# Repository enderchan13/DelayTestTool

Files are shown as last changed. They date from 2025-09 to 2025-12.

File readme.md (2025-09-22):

# 磁轴键盘延时测试器

## 概述

磁轴键盘延时测试器是一个专为磁轴键盘设计的自动化测试工具，用于精确测量按键的**按下延迟**和**抬起延迟**。它通过**通电线圈模拟磁铁**，用曲线拟合人手按压和释放过程，避免市面上使用机械按压结构加摄像机分帧的测量方式造成的静态误差和随机干扰，整个过程精准可控且最大限度贴近人手使用模式。除了可测量单键的全链路延迟之外，也支持多键和SOCD的延时测试。测试器通过多次快速触发测量平均延迟，提供高精度、可重复的测试结果。本项目适用于键盘制造商、硬件测试人员及键盘爱好者。

## 功能特性

- **极限工况测试**：支持极限快速、极限低速、真实按压等多种不同测试工况的模拟测试
- **自动化测试**：通过通电线圈模拟磁铁触发磁轴开关，消除手动按压的不一致性
- **高精度测量**：支持微秒级延迟检测（精度可达±0.1ms）
- **可重复测试**：支持多次快速触发，计算平均延迟
- **兼容性**：支持常见磁轴键盘（如霍尔效应、磁感应开关）
- **数据显示**：测试结果将直接展示在测试器屏幕

## 系统架构

### 硬件组件

1. **主控制器**：沁恒CH32V305RBT6（支持USB HID通信）
2. **线圈驱动电路**：LDO电路（如D2652-AD）控制通电线圈模拟磁铁动作
3. **线圈驱动接口**：直接连接线圈轴体
4. **电源接口**：直接连接5V/2A直流电源（为线圈和控制器供电）
4. **PC接口**：直接连接电脑（可进行测试器固件升级更新）
4. **USB主机接口**：直接连接待测试磁轴键盘（对键盘进行延时测试）

### 软件组件

1. **固件**（C/C++）：识别接入到测试器的磁轴键盘，控制线圈触发时序对键盘进行延时测试
2. **测试逻辑**：
   - 识别接入的待测试键盘
   - 发送触发信号并记录时间戳
   - 计算按下延迟（从线圈磁场模拟按下到键盘发送按下报文）和抬起延迟（从线圈磁场模拟释放到键盘发送抬起报文）
   - 循环多次测试并统计结果

## 安装与使用

### 硬件连接

1. 将线圈固定在磁轴键盘的待测按键上方（确保与磁轴对齐）
2. 连接线圈到线圈驱动接口
3. 电源供电（5V适配器或USB）
4. 连接磁轴键盘到测试器USB主机接口（USB线）

### 固件升级

1. 安装WCHISPTool_Setup（安装包路径Tools/WCHISPTool_Setup）
2. 打开本项目固件文件 `BinFiles/DelayTestTool_v0.0.2_20250912a`
3. 按下BOOT按键连接到WCH芯片
4. 下载固件

### 文档资料

1. 测试器硬件原理图、PCB以及BOM资料路径/Docs/Hardware/
2. 测试器操作说明资料路径/Docs/UserManual/
3. 测试器操作教程、升级教程以及原理讲解视频资料路径/Docs/Vedio/

### 使用说明
- 测试器使用步骤详情见Docs/UserManual/<延时测试器操作说明.pdf>

## 许可证
- 本项目根据**GNU通用公共许可证v2.0**或者更高版本授权。
- 完整的许可证文本请参阅**LICENSE**文件。

## 注意事项
1. 安全使用：线圈驱动过久会发热严重，请谨慎操作，避免烫伤
2. 校准建议：首次使用时需根据键盘类型进行按键校准和测试模式配置（详情见 Docs/<延时测试器操作说明.pdf>）
3. 兼容性：目前支持常见磁轴键盘（如XSYD、Wooting、MelGeek等）
4. 故障排除：如果测试结果异常，检查线圈轴体是否安装到位或者或者其他错误操作（详情见Docs/<延时测试器操作说明.pdf>）

## 致谢
- 灵感来自磁轴键盘测试需求及开源社区讨论

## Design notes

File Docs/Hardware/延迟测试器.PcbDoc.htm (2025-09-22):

Reporting Options

# File in Newer Format

Date | : | 2025/9/22
Time | : | 10:21:12
Filename | : | E:\repository\DelayTestTool\Docs\Hardware\延迟测试器.PcbDoc

Version | Warning
Release 23.6 | CAUTION - The PCB document contains Footprint parameters. These will be lost when opening the document in a version of Altium Designer that does not support this functionality.

This file was generated by a later version of the software

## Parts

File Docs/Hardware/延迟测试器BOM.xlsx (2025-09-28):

延迟测试器BOM
Class | Comment | Description | Designator | Footprint | Quantity | interlinkage | picture | PS
贴片电容 | 1000pF/2kV | 1000pF/K/2KV/X7R/1206 | C1, C11 | C 1206_L | 2 | https://so.szlcsc.com/global.html?k=C9196&hot-key=STM32F103C8T6
贴片电容 | 100nF | 100nF/±10%/50V/X7R/0603 | C2, C3, C10, C14, C15, C16, C17, C23, C26 | C 0603_L | 9 | https://so.szlcsc.com/global.html?k=C14663&hot-key=STM32F103C8T6
钽电容 | 22uF钽电容 | 22uF/±10%/CA45/A/10V/1206 | C4, C5, C21 | CDA1206 | 3 | https://so.szlcsc.com/global.html?k=C6143460&hot-key=STM32F103C8T6
钽电容 | 47uF钽电容 | 47uF/±10%/CA45/B/10V/3528 | C6 | CD B(3528) | 1 | https://so.szlcsc.com/global.html?k=C123253&hot-key=STM32F103C8T6
贴片电容 | 10uF | 10uF/±10%/10V/X5R/0603 | C9, C18, C19, C20, C22 | C 0603_L | 5 | https://so.szlcsc.com/global.html?k=C19702&hot-key=STM32F103C8T6
贴片电容 | 12pF | 12pF/±5%/50V/NPO/0603 | C12, C13 | C 0603_L | 2 | https://so.szlcsc.com/global.html?k=C107034&hot-key=STM32F103C8T6
贴片电阻 | 10k | 10k/±5%/100mW/75V/±100ppm/℃/0603 | R1, R7, R15, R17, R18, R19, R20, R22, R23, R24 | R 0603_L | 10 | https://so.szlcsc.com/global.html?k=C2930027&hot-key=STM32F103C8T6
贴片电阻 | 1M | 1M/±5%/1206 | R2, _x0003_R1 | R 1206_L | 2 | https://so.szlcsc.com/global.html?k=C2907441&hot-key=STM32F103C8T6
贴片电阻 | 1k | 1k/±5%/1/10W/0603 | R5, R10, R21 | R 0603_L | 3 | https://so.szlcsc.com/global.html?k=C22356624&hot-key=STM32F103C8T6
贴片电阻 | 62R | 62R/±5%/1/10W/0603 | R8 | R 0603_L | 1 | https://so.szlcsc.com/global.html?k=C2907193&hot-key=STM32F103C8T6
贴片电阻 | 5.1k | 5.1k/±5%/1/10W/0603 | R9, R13, R14, R16 | R 0603_L | 4 | https://so.szlcsc.com/global.html?k=C26000&hot-key=STM32F103C8T6
贴片电阻 | 0R | 0R/±5%/1/10W/0603 | R11, R12, R25, R26 | R 0603_L | 4 | https://so.szlcsc.com/global.html?k=C2907080&hot-key=STM32F103C8T6
磁珠 | 90R/100MHZ/NC | 90R/100MHZ/NC | L1, L3 | 2012-L | 0 |  |  | NC
IC | CE6210A33P | CE6210A33P/SOT89-3 | U1 | SOT89-3 | 1 | 【淘宝】https://e.tb.cn/h.SX97oUnxk7mCEgo?tk=crG34ufWmXE MF278 「CE6210A33P 封装SOT89-3 LDO稳压IC 原装」
MCU | CH32V305RBT6 | CH32V305RBT6/LQFP64 10x10_M | U2 | LQFP64 10x10_M | 1 | https://so.szlcsc.com/global.html?k=C5187529&hot-key=STM32F103C8T6
TVS管 | USBLC6-2SC6 | USBLC6-2SC6/TVS管/SOT23-6 | D1 | SOT23-6M | 1 | https://so.szlcsc.com/global.html?k=C2827654&hot-key=STM32F103C8T6
晶振 | 24MHZ | Y3225/24MHZ/12pF/10ppM | X1 | OSC 3225-4P | 1 | https://so.szlcsc.com/global.html?k=C164058&hot-key=STM32F103C8T6
TYPE-C | USB TYPE C | TYPE C 16PIN板上型7.35MM 三模母座 带弹片 短舌口 | USB1, USB2 | TYPE-C 16PIN 2MD(073) | 2 | https://so.szlcsc.com/global.html?k=C2840391&hot-key=STM32F103C8T6
TYPE-C | USB母座 | USB-A型母接口 | USB3 | USB-A/S_B | 1 | https://so.szlcsc.com/global.html?k=C404963&hot-key=STM32F103C8T6 | =DISPIMG("ID_FE9C9ED8A97D4D97BB3E7B776DAC5DDF",1)
轻触开关 | 3x6x5 | TS-1009S-03826/3x6x5轻触开关支架 | SW1 | SW-SMD_L6.0-W3.3-LS8.0 | 1 | https://so.szlcsc.com/global.html?k=C18078124&hot-key=STM32F103C8T6 | =DISPIMG("ID_B56FF27C85AE4D59906D2A8A2305ED9A",1)
轻触开关 | 3x6x5 | 3x6x5轻触开关/TS-1101-C-W | SW2, SW3, SW4, SW5 | SW-TH_4P-L7.4-W5.0-P5.0 | 4 | https://so.szlcsc.com/global.html?k=C318938&hot-key=STM32F103C8T6 | =DISPIMG("ID_A550F3A074CA4E69AD2A6719362A980A",1)
肖特基二极管 | SS24 | SS24/肖特基二极管/SMA | D2, D3 | SMA | 2 | https://so.szlcsc.com/global.html?k=C7420362&hot-key=STM32F103C8T6
FPC连接器 | 屏幕接口 | FPC0.5*8P/抽屉式/下接/卧贴 | FPC1 | FPC-SMD_AFC07-S08FCA-00 | 1 | https://so.szlcsc.com/global.html?k=C262555&hot-key=STM32F103C8T6
高频放大-PNP型 | SS8550 | SS8550/SOT23L | Q1 | SOT23L | 1 | https://so.szlcsc.com/global.html?k=C916393&hot-key=STM32F103C8T6
LDO | D2652-AD | D2652-AD/TO-263-5 | U3 | TO-263-5_L10.2-W8.9-P1.70-TL-LS15.2 | 1 | https://so.szlcsc.com/global.html?k=C2837289&hot-key=STM32F103C8T6
DC002母头 | DC-002-2.0A-1.3 | DC-002-2.0A-1.3/DC002母头 | DC1 | DC-IN-TH_DC-002-2.0A-1.3 | 1 | https://item.taobao.com/item.htm?_u=p2bbhg32ebef&id=723232233042&skuId=5025121028404 | =DISPIMG("ID_BE2CEAD91BA34B32A4C57BDFE3A3CF18",1)
双通铜柱 | M2*8mm | M2*8mm/双通铜柱 | / | / | 4 | https://detail.tmall.com/item.htm?from=cart&id=16356181954&skuId=5053912691569&upStreamPrice=189 | =DISPIMG("ID_EE856DFD05E440A9B50BE96DF4F012FB",1)
双通铜柱 | M2*5+3mm | M2*5+3mm/双通铜柱 | / | / | 4 | https://detail.tmall.com/item.htm?from=cart&id=16356181954&skuId=5053912691564&upStreamPrice=189 | =DISPIMG("ID_C07D0C5867C04F448279E9EA2559F678",1)
十字圆头螺丝 | M2*4mm | M2*4mm/十字圆头螺丝 | / | / | 8 | https://detail.tmall.com/item.htm?from=cart&id=17088123342&skuId=4890861585220&upStreamPrice=469 | =DISPIMG("ID_9D3E65D7E90D44AEA3553F17F033701D",1)
DC002公头带线 | DC3.5x1.35公头线-30CM | DC3.5x1.35公头线-30CM | / | / | 1 | https://item.taobao.com/item.htm?_u=p2bbhg32e2a0&id=614222721679&skuId=4496351122376 | =DISPIMG("ID_CDFD7AB1DBFA4879A2FF8B23AB24BD7A",1)
彩色热塑管 | φ2mm | φ2mm/长度45mm | / | / | 1 | https://detail.tmall.com/item.htm?id=735286048821
彩色热塑管 | φ5mm | φ5mm/长度45mm | / | / | 1 | https://detail.tmall.com/item.htm?id=735286048821
彩色热塑管 | φ10mm | φ10mm/长度45mm | / | / | 1 | https://detail.tmall.com/item.htm?id=735286048821
屏幕 | 1.14 | 1.14/屏幕 | / | / | 1 | 【淘宝】https://e.tb.cn/h.SXrZcfo6Hd8iDyt?tk=ZNrl4u4WRug HU293 「1.14寸TFT液晶屏st7789驱动135x240高清显示LCD长条形屏SPI彩屏幕」 点击链接直接打开 或者 淘宝搜索直接打开 | =DISPIMG("ID_6B6917046DC74415807B5AD36ADE6ADC",1)
亚克力板子 | 54.2*35.2*2mm | 54.2*35.2*2mm/亚克力板子 | / | / | 2 | 【淘宝】7天无理由退货 https://e.tb.cn/h.SWVldsaU9S1TlKb?tk=qae54vo9EIr CZ057 「定制加工高透明亚克力板有机玻璃塑料板热弯印刷雕刻展示盒PMMA板」 点击链接直接打开 或者 淘宝搜索直接打开 | =DISPIMG("ID_838DD5E48F22457A873292679A285B84",1)
线圈 | 定制 |  | / | 用猛锌铁氧体材料，直径6mm*长度39mm，用0.4mm的漆包线绕5层（找客服定制） | 1 | 【淘宝】https://e.tb.cn/h.S4bxYEJ5Le5NJKq?tk=TJ4y4xEsE35 HU108 「中周成品定制 线圈定制 调幅中波中周中频变压器 可调节磁帽磁芯」 点击链接直接打开 或者 淘宝搜索直接打开 | =DISPIMG("ID_3CDE111D44D54F87A5B2880B30020D5A",1)
PCBA尺寸：54.2mm*35.18mm

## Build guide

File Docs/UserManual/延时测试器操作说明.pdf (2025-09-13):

## 延时测试器操作说明

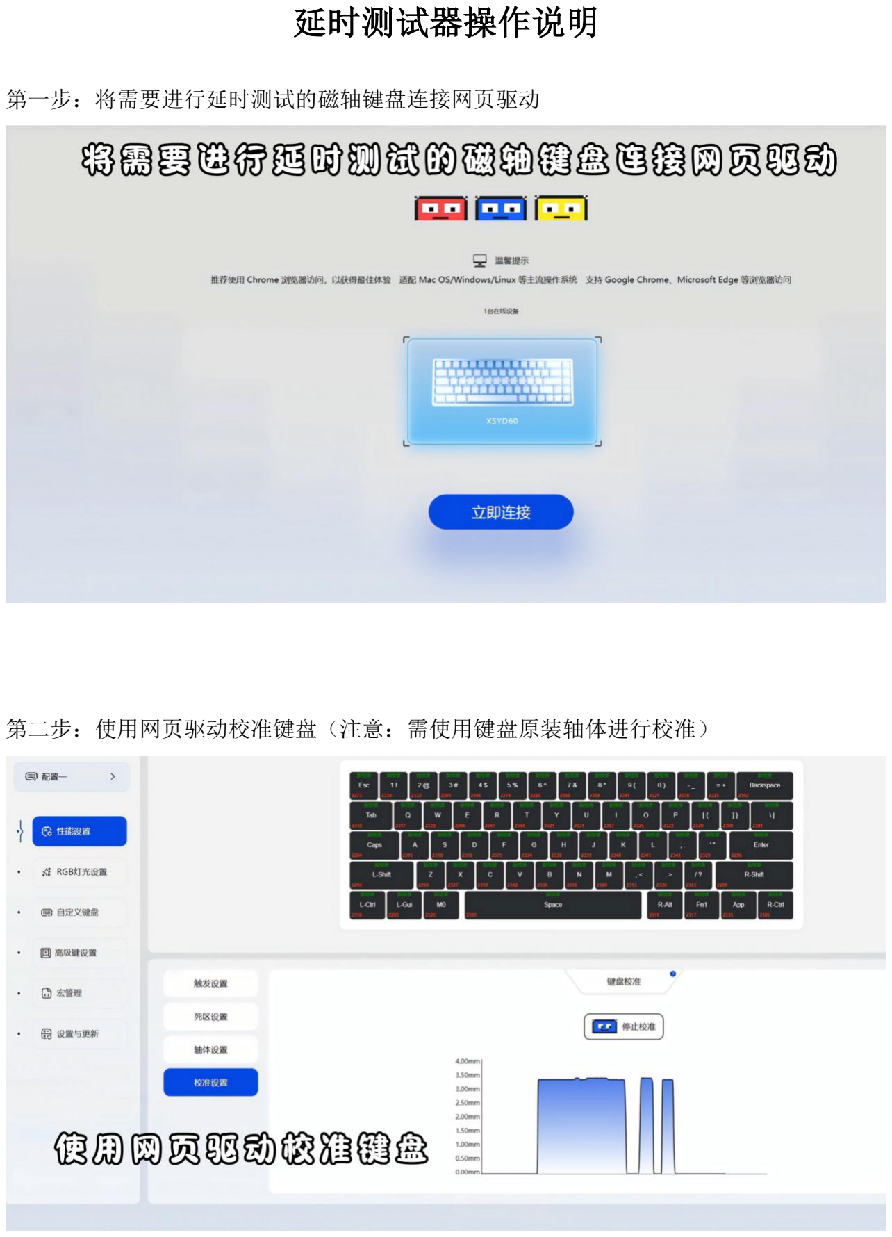
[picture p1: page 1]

第一步：将需要进行延时测试的磁轴键盘连接网页驱动

第二步：使用网页驱动校准键盘（注意：需使用键盘原装轴体进行校准）

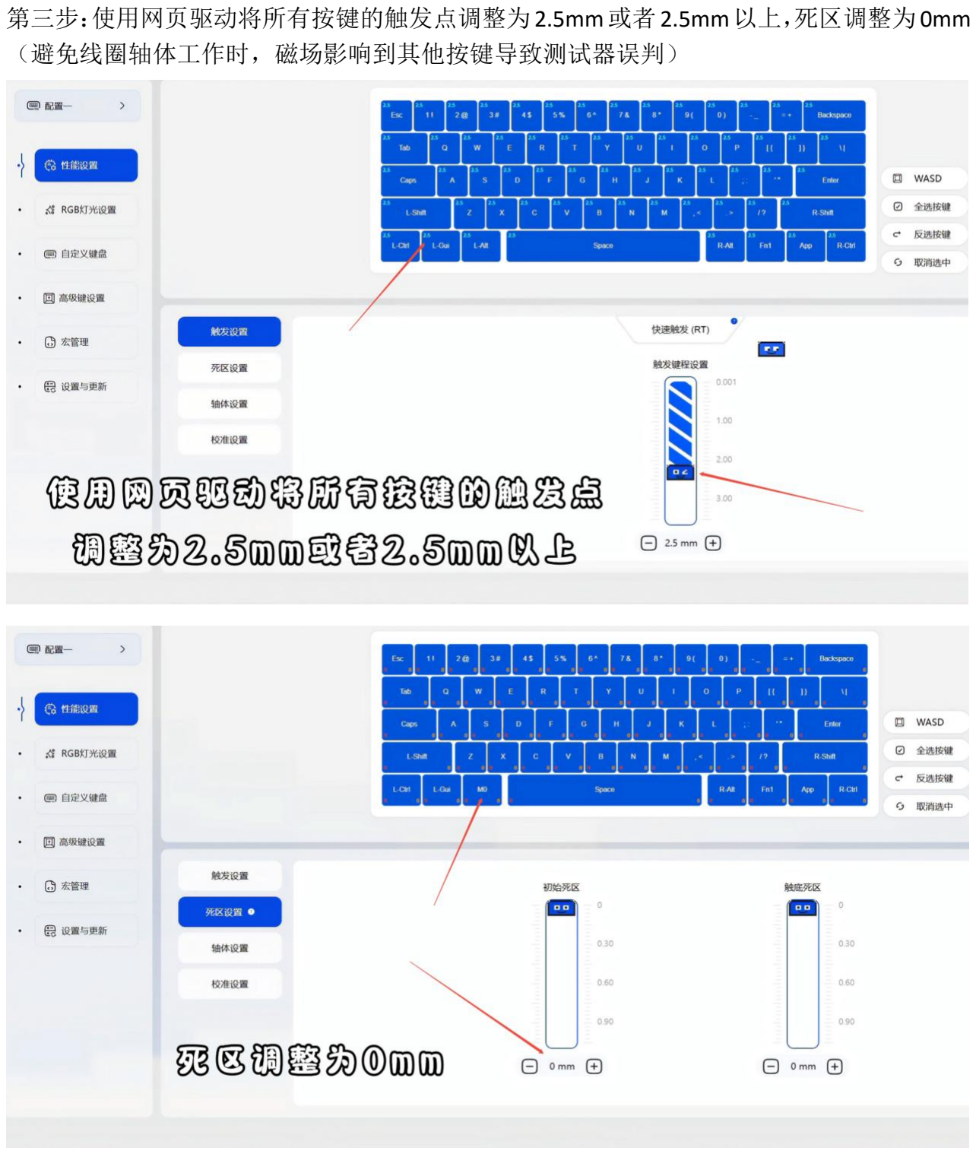
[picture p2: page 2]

第三步：使用网页驱动将所有按键的触发点调整为2.5mm或者2.5mm以上，死区调整为0mm （避免线圈轴体工作时，磁场影响到其他按键导致测试器误判）

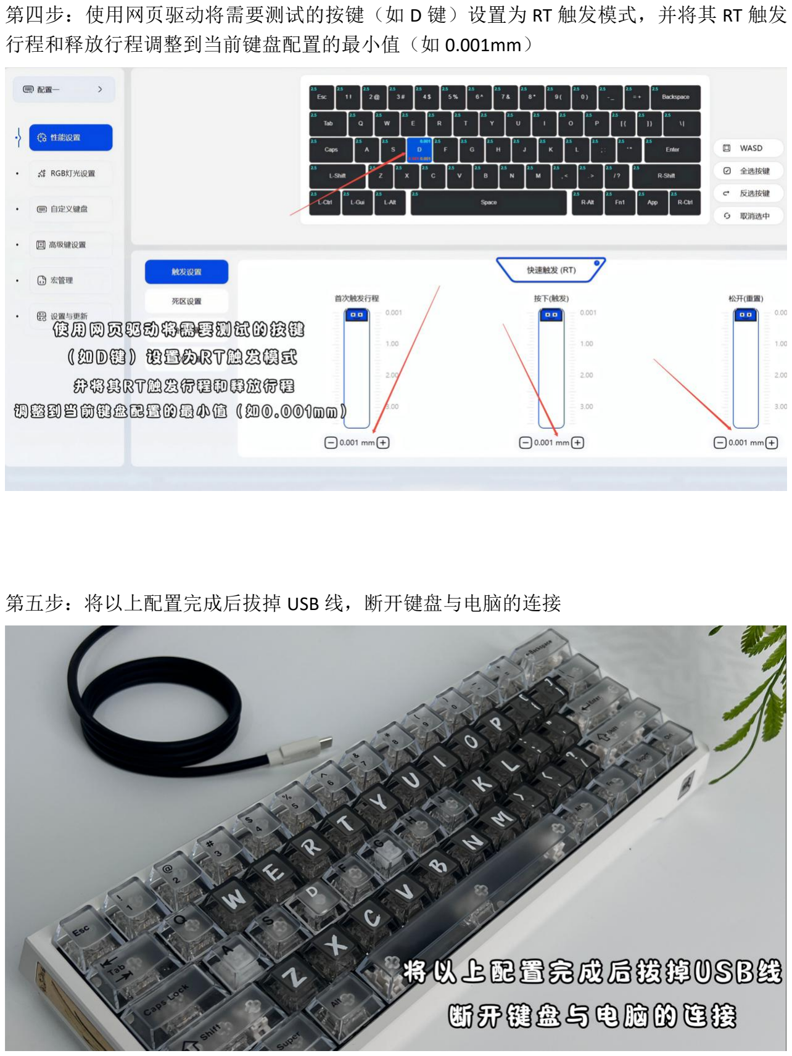
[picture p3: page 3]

第四步：使用网页驱动将需要测试的按键（如 D 键）设置为 RT 触发模式，并将其 RT 触发 行程和释放行程调整到当前键盘配置的最小值（如 0.001mm）

第五步：将以上配置完成后拔掉 USB 线，断开键盘与电脑的连接

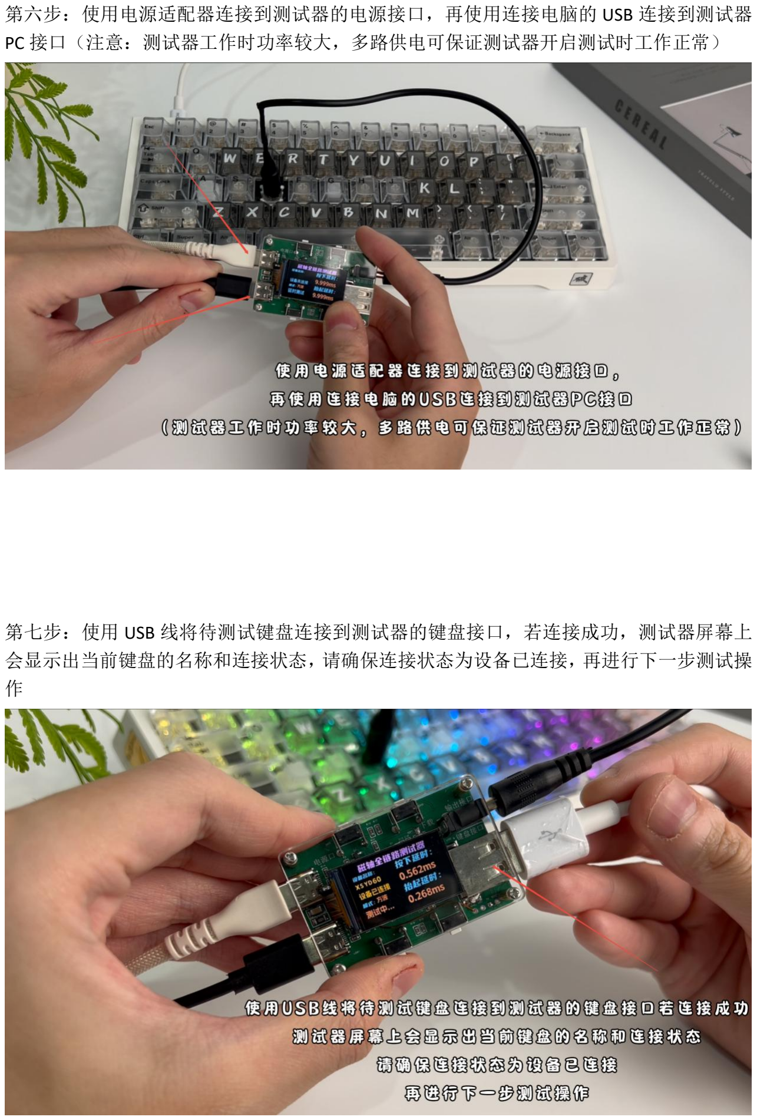
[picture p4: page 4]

第六步：使用电源适配器连接到测试器的电源接口，再使用连接电脑的 USB 连接到测试器 PC 接口（注意：测试器工作时功率较大，多路供电可保证测试器开启测试时工作正常）

第七步：使用 USB 线将待测试键盘连接到测试器的键盘接口，若连接成功，测试器屏幕上 会显示出当前键盘的名称和连接状态，请确保连接状态为设备已连接，再进行下一步测试操 作

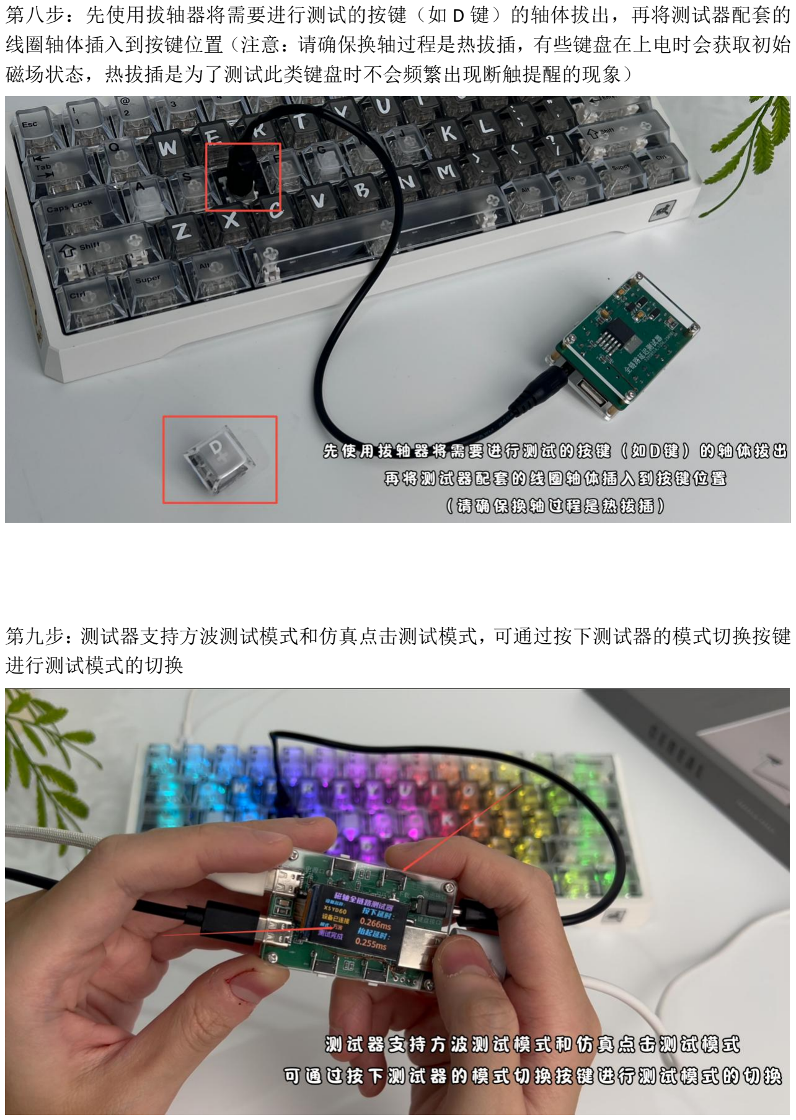
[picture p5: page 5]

第八步：先使用拔轴器将需要进行测试的按键（如 D 键）的轴体拔出，再将测试器配套的 线圈轴体插入到按键位置（注意：请确保换轴过程是热拔插，有些键盘在上电时会获取初始 磁场状态，热拔插是为了测试此类键盘时不会频繁出现断触提醒的现象）

第九步：测试器支持方波测试模式和仿真点击测试模式，可通过按下测试器的模式切换按键 进行测试模式的切换

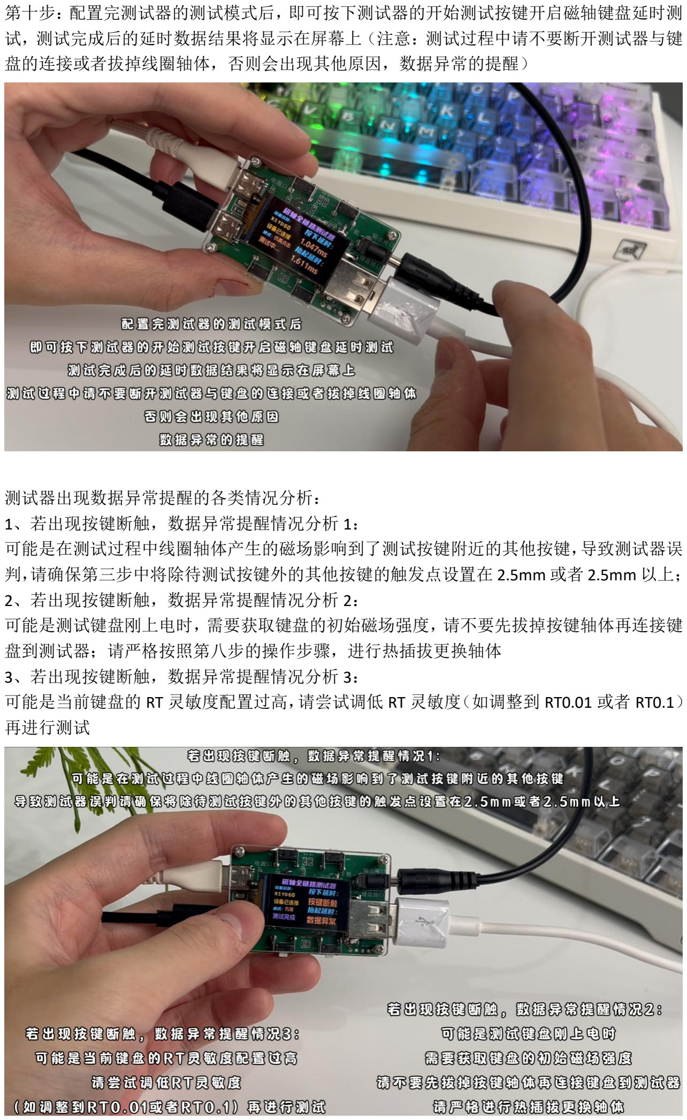
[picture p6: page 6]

第十步：配置完测试器的测试模式后，即可按下测试器的开始测试按键开启磁轴键盘延时测 试，测试完成后的延时数据结果将显示在屏幕上（注意：测试过程中请不要断开测试器与键 盘的连接或者拔掉线圈轴体，否则会出现其他原因，数据异常的提醒）

测试器出现数据异常提醒的各类情况分析：
1、若出现按键断触，数据异常提醒情况分析 1：
可能是在测试过程中线圈轴体产生的磁场影响到了测试按键附近的其他按键，导致测试器误 判，请确保第三步中将除待测试按键外的其他按键的触发点设置在 2.5mm 或者 2.5mm 以上； 2、若出现按键断触，数据异常提醒情况分析 2：
可能是测试键盘刚上电时，需要获取键盘的初始磁场强度，请不要先拔掉按键轴体再连接键 盘到测试器；请严格按照第八步的操作步骤，进行热插拔更换轴体 3、若出现按键断触，数据异常提醒情况分析 3：
可能是当前键盘的 RT 灵敏度配置过高，请尝试调低 RT 灵敏度（如调整到 RT0.01 或者 RT0.1） 再进行测试

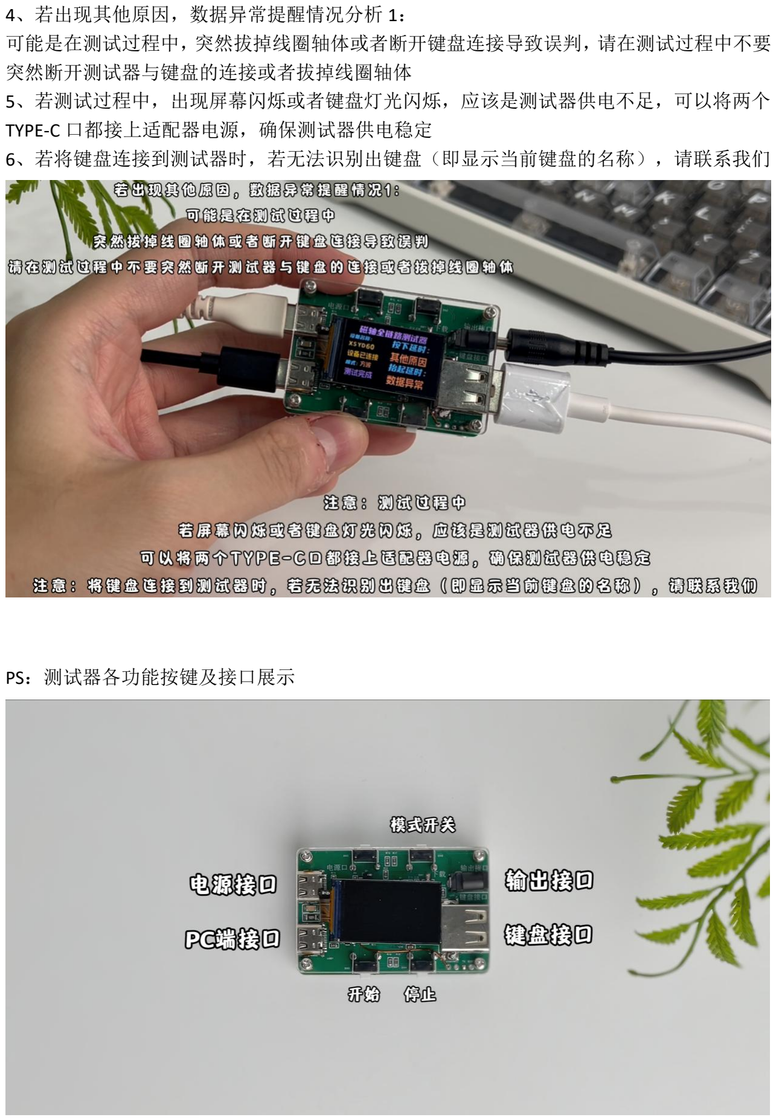
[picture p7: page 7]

4、若出现其他原因，数据异常提醒情况分析 1：
可能是在测试过程中，突然拔掉线圈轴体或者断开键盘连接导致误判，请在测试过程中不要 突然断开测试器与键盘的连接或者拔掉线圈轴体
5、若测试过程中，出现屏幕闪烁或者键盘灯光闪烁，应该是测试器供电不足，可以将两个 TYPE-C 口都接上适配器电源，确保测试器供电稳定 6、若将键盘连接到测试器时，若无法识别出键盘（即显示当前键盘的名称），请联系我们

PS：测试器各功能按键及接口展示

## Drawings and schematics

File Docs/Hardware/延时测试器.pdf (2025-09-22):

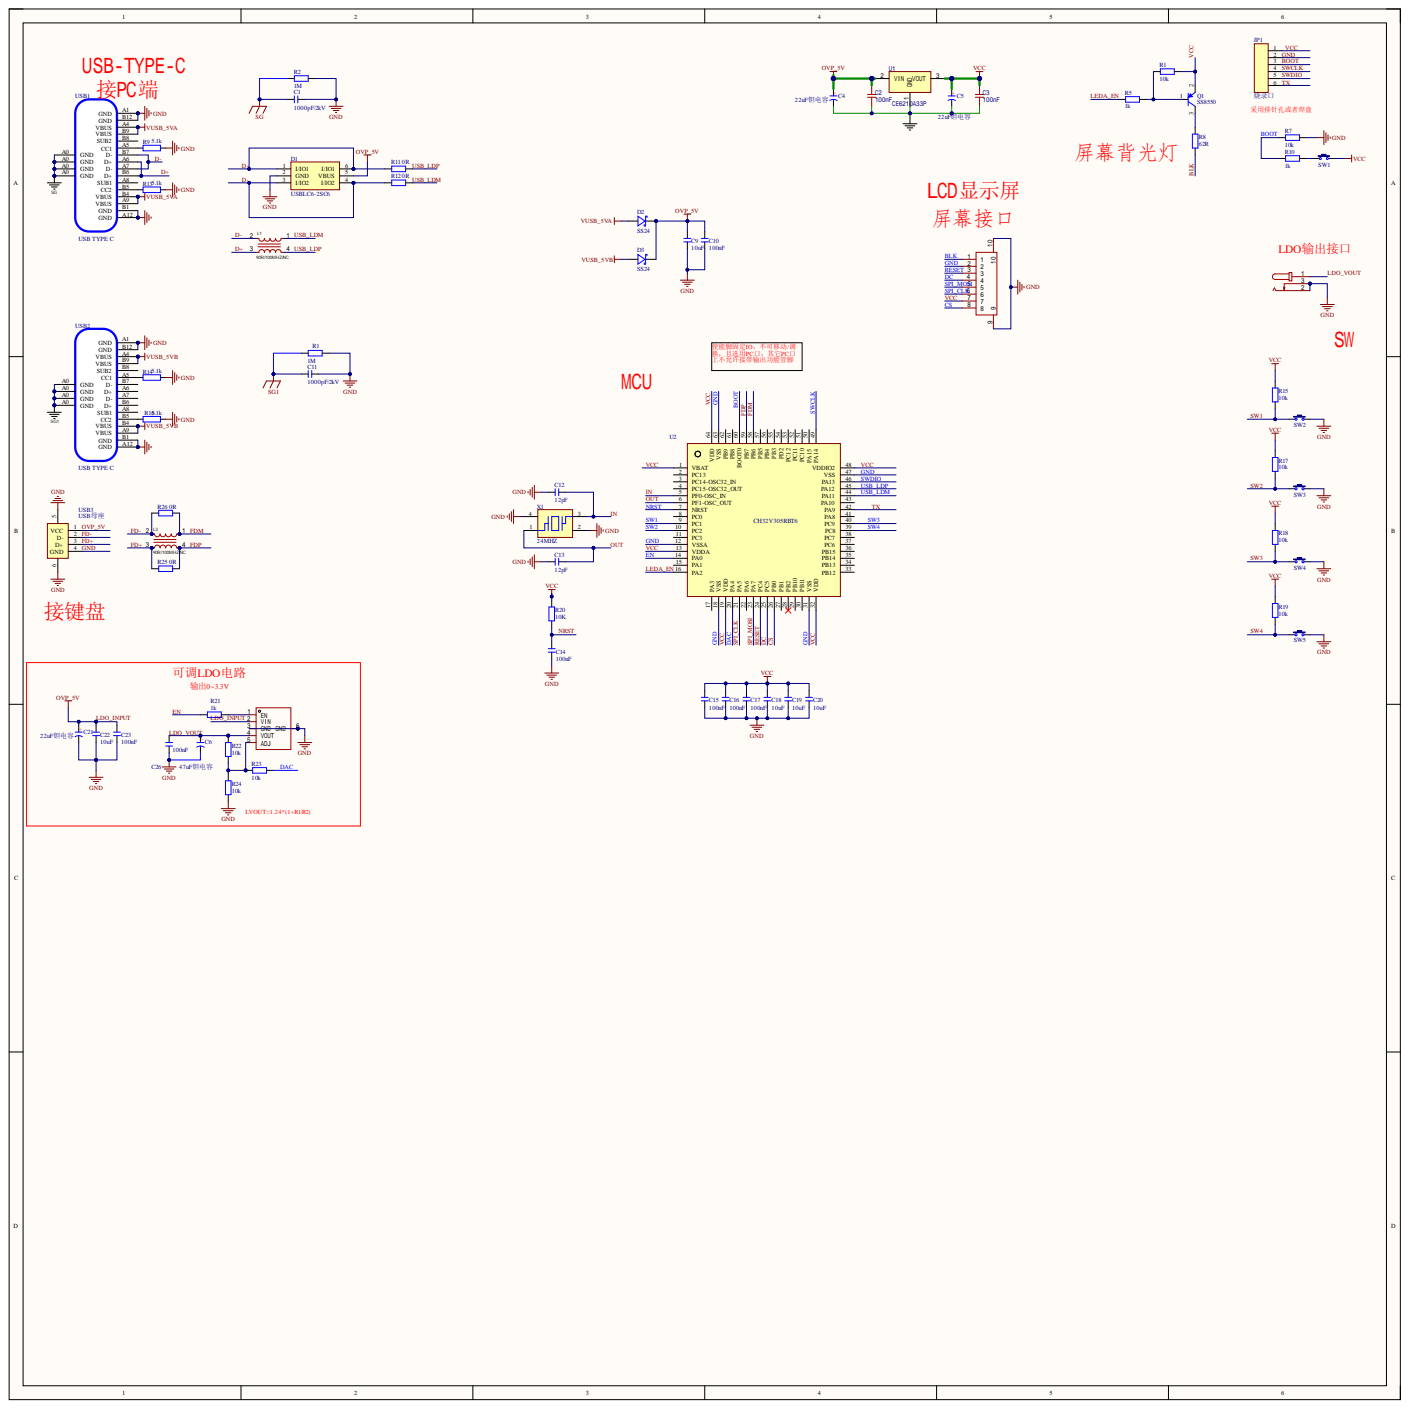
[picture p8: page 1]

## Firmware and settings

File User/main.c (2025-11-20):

/* Copyright 2025 Ender Chan (Ender)
 *
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
 * You should have received a copy of the GNU General Public License
 * along with this program.  If not, see <http://www.gnu.org/licenses/>.
 */

/* Header Files */
#include "usb_host_config.h"
#include "tim.h"
#include "lcd.h"
#include "key.h"

#define DELAY_TEST_CNT 100
#define WAVE_TRIGGER_DAC_VALUE 2000
#define WAVE_RELEASE_DAC_VALUE 3500
#define SINE_WAVE_POINTS 1000

static volatile uint32_t waveIndex = 0;

uint8_t  product_name[20];          /* 设备名称 */
uint8_t  dev_sta = 0;               /* 设备状态 */
uint32_t press_delay = 9999;        /* 按下延时 */
uint32_t lift_delay  = 9999;        /* 抬起延时 */
uint8_t  test_mode = 0;             /* 测试模式 */
uint8_t  test_sta = 0;              /* 测试状态 */
uint8_t  test_cnt = DELAY_TEST_CNT; /* 测试次数 */
uint8_t  test_cnt_mode = 0;         /* 测试次数模式 */
uint16_t key_trigger_cnt = 0;       /* 一次测试的多键判断计数 */
uint16_t multi_key_Judg_cnt = 0;    /* 一次按下/抬起动作的多键判断计数 */
uint8_t  test_trig_first_flag = 0;  /* 测试过程中首次触发标志， */

uint8_t  square_wave_flag = 0;              /* 方波开启标志 */
uint16_t square_wave_cnt = 0;               /* 方波周期计数 */
uint32_t square_wave_time = 0;              /* 方波计时器 */
uint8_t  square_single_press_flag = 0;      /* 方波按下标志 */
uint8_t  square_single_release_flag = 0;    /* 方波抬起标志 */
uint32_t square_single_trigger_cnt  = 0;    /* 方波按下计数器 */
uint32_t square_single_release_cnt  = 0;    /* 方波抬起计数器 */
uint16_t square_trigger_delay_time_buf[DELAY_TEST_CNT] = {0};   /* 方波按下延时数据缓存 */
uint16_t square_release_delay_time_buf[DELAY_TEST_CNT] = {0};   /* 方波抬起延时数据缓存 */ 
uint32_t square_trigger_delay_time = 0;     /* 方波按下平均延时 */
uint32_t square_release_delay_time = 0;     /* 方波抬起平均延时 */
uint8_t  square_data_invalid = 0;           /* 方波数据有效标志 */
uint8_t  square_trigger_sta = 0;            /* 方波高低电平状态 */

uint8_t  triangle_wave_flag = 0;            /* 三角波开启标志 */
uint32_t triangle_wave_cnt = 0;             /* 三角波周期计数 */
uint32_t triangle_wave_time = 0;            /* 三角波计时器 */
uint8_t  triangle_wave_press_flag = 0;      /* 三角波按下标志 */
uint8_t  triangle_wave_release_flag = 0;    /* 三角波抬起标志 */
uint32_t triangle_single_trigger_cnt = 0;   /* 三角波按下计数器 */
uint32_t triangle_single_release_cnt = 0;   /* 三角波抬起计数器 */
uint16_t triangle_trigger_delay_time_buf[DELAY_TEST_CNT] = {0};     /* 三角波按下延时数据缓存 */
uint16_t triangle_release_delay_time_buf[DELAY_TEST_CNT] = {0};     /* 三角波抬起延时数据缓存 */
uint32_t triangle_trigger_delay_time = 0;   /* 三角波按下平均延时 */
uint32_t triangle_release_delay_time = 0;   /* 三角波抬起平均延时 */
uint8_t  triangle_data_invalid = 0;         /* 三角波数据有效标志 */

uint8_t  simulation_curve_flag = 0;         /* 仿真点击开启标志 */
uint32_t simulation_curve_cnt = 0;          /* 仿真点击周期计数 */
uint32_t simulation_curve_time = 0;         /* 仿真点击计时器 */
uint8_t  simulation_curve_press_flag = 0;   /* 仿真点击按下标志 */
uint8_t  simulation_curve_release_flag = 0; /* 仿真点击抬起标志 */
uint32_t simulation_curve_single_trigger_cnt = 0;   /* 仿真点击按下计数器 */
uint32_t simulation_curve_single_release_cnt = 0;   /* 仿真点击抬起计数器 */
uint16_t simulation_curve_trigger_delay_time_buf[DELAY_TEST_CNT] = {0};     /* 仿真点击按下延时数据缓存 */
uint16_t simulation_curve_release_delay_time_buf[DELAY_TEST_CNT] = {0};     /* 仿真点击抬起延时数据缓存 */
uint32_t simulation_curve_trigger_delay_time = 0;   /* 仿真点击按下平均延时 */
uint32_t simulation_curve_release_delay_time = 0;   /* 仿真点击抬起平均延时 */
uint8_t  simulation_curve_data_invalid = 0;         /* 仿真点击数据有效标志 */
uint32_t simulation_curve_timeout = 0;              /* 仿真点击周期超时计数器 */

static uint16_t sineWaveTable[SINE_WAVE_POINTS] = {
    2000, 2000, 2000, 2000, 2000, 2000, 2000, 2000, 2000, 2000,
    2000, 2000, 2000, 2000, 2000, 2000, 2000, 2000, 2000, 2000,
    2000, 2000, 2000, 2000, 2000, 2000, 2000, 2000, 2000, 2000,
    2000, 2000, 2000, 2000, 2000, 2000, 2000, 2000, 2000, 2000,
    2000, 2000, 2000, 2000, 2000, 2000, 2000, 2000, 2000, 2000,
    2000, 2000, 2000, 2000, 2000, 2000, 2000, 2000, 2000, 2000,
    2000, 2000, 2000, 2000, 2000, 2000, 2000, 2000, 2000, 2000,
    2000, 2000, 2000, 2000, 2000, 2000, 2000, 2000, 2000, 2000,
    2000, 2000, 2000, 2000, 2000, 2000, 2000, 2000, 2000, 2000,
    2000, 2000, 2000, 2000, 2000, 2000, 2000, 2000, 2000, 2000,
    2000, 2000, 2000, 2000, 2000, 2000, 2000, 2000, 2000, 2000,
    2000, 2000, 2000, 2000, 2000, 2000, 2000, 2000, 2000, 2000,
    2000, 2000, 2000, 2000, 2000, 2000, 2000, 2000, 2000, 2000,
    2000, 2000, 2000, 2000, 2000, 2000, 2000, 2000, 2000, 2000,
    2000, 2000, 2000, 2000, 2000, 2000, 2000, 2000, 2000, 2000,
    2000, 2000, 2000, 2000, 2000, 2000, 2000, 2000, 2000, 2000,
    2000, 2000, 2000, 2000, 2000, 2000, 2000, 2000, 2000, 2000,
    2000, 2000, 2000, 2000, 2000, 2000, 2000, 2000, 2000, 2000,
    2000, 2000, 2000, 2000, 2000, 2000, 2000, 2000, 2000, 2000,
    2000, 2000, 2000, 2000, 2000, 2000, 2000, 2000, 2000, 2000,
    2000, 2000, 2000, 2000, 2000, 2000, 2000, 2000, 2000, 2000,
    2000, 2000, 2000, 2000, 2000, 2000, 2000, 2000, 2000, 2000,
    2000, 2000, 2000, 2000, 2000, 2000, 2000, 2000, 2000, 2000,
    2000, 2000, 2000, 2000, 2000, 2000, 2000, 2000, 2000, 2000,
    2000, 2000, 2000, 2000, 2000, 2000, 2000, 2000, 2000, 2000,
    2000, 2000, 2000, 2000, 2000, 2000, 2000, 2000, 2000, 2000,
    2000, 2000, 2000, 2000, 2000, 2000, 2000, 2000, 2000, 2000,
    2000, 2000, 2000, 2000, 2000, 2000, 2000, 2000, 2000, 2000,
    2000, 2000, 2000, 2000, 2000, 2000, 2000, 2000, 2000, 2000,
    2000, 2000, 2000, 2000, 2000, 2000, 2000, 2000, 2000, 2000,
    2000, 2000, 2000, 2000, 2000, 2000, 2000, 2000, 2000, 2000,
    2000, 2000, 2000, 2000, 2000, 2000, 2000, 2000, 2000, 2000,
    2000, 2000, 2000, 2000, 2000, 2000, 2000, 2000, 2000, 2000,
    2000, 2000, 2000, 2000, 2000, 2000, 2000, 2000, 2000, 2000,
    2000, 2000, 2000, 2000, 2000, 2000, 2000, 2000, 2000, 2000,
    2000, 2000, 2000, 2000, 2000, 2000, 2000, 2000, 2000, 2000,
    2000, 2000, 2000, 2000, 2000, 2000, 2000, 2000, 2000, 2000,
    2000, 2000, 2000, 2000, 2000, 2000, 2000, 2000, 2000, 2000,
    2000, 2000, 2000, 2000, 2000, 2000, 2000, 2000, 2000, 2000,
    2000, 2000, 2000, 2000, 2000, 2000, 2000, 2000, 2000, 2000,

    2000, 2000, 2000, 2000, 2000, 2000, 2000, 2000, 2000, 2000,
    2000, 2000, 2000, 2000, 2000, 2000, 2000, 2000, 2000, 2000,
    2000, 2000, 2000, 2000, 2000, 2000, 2000, 2000, 2000, 2000,
    2000, 2001, 2002, 2005, 2007, 2010, 2012, 2016, 2019, 2021,
    2025, 2028, 2031, 2036, 2041, 2045, 2050, 2056, 2061, 2066,
    2072, 2077, 2083, 2089, 2096, 2102, 2107, 2114, 2119, 2125,
    2132, 2139, 2147, 2155, 2164, 2172, 2180, 2190, 2199, 2210,
    2222, 2234, 2247, 2260, 2274, 2290, 2305, 2321, 2337, 2354,
    2373, 2391, 2410, 2429, 2449, 2470, 2492, 2513, 2535, 2557,
    2580, 2603, 2626, 2649, 2672, 2695, 2718, 2742, 2765, 2789,
    2812, 2836, 2860, 2883, 2906, 2929, 2951, 2973, 2994, 3015,
    3037, 3057, 3077, 3098, 3118, 3136, 3156, 3173, 3191, 3208,
    3226, 3243, 3259, 3275, 3291, 3306, 3320, 3334, 3348, 3361,
    3373, 3385, 3396, 3408, 3419, 3430, 3442, 3453, 3462, 3471,
    3481, 3490, 3495, 3498, 3498, 3499, 3500, 3500, 3500, 3500,

    3500, 3500, 3500, 3500, 3500, 3500, 3500, 3500, 3500, 3500,
    3500, 3500, 3500, 3500, 3500, 3500, 3500, 3500, 3500, 3500,
    3500, 3500, 3500, 3500, 3500, 3500, 3500, 3500, 3500, 3500,
    3500, 3500, 3500, 3500, 3500, 3500, 3500, 3500, 3500, 3500,
    3500, 3500, 3500, 3500, 3500, 3500, 3500, 3500, 3500, 3500,
    3500, 3500, 3500, 3500, 3500, 3500, 3500, 3500, 3500, 3500,
    3500, 3500, 3500, 3500, 3500, 3500, 3500, 3500, 3500, 3500,
    3500, 3500, 3500, 3500, 3500, 3500, 3500, 3500, 3500, 3500,
    3500, 3500, 3500, 3500, 3500, 3500, 3500, 3500, 3500, 3500,
    3500, 3500, 3500, 3500, 3500, 3500, 3500, 3500, 3500, 3500,
    3500, 3500, 3500, 3500, 3500, 3500, 3500, 3500, 3500, 3500,
    3500, 3500, 3500, 3500, 3500, 3500, 3500, 3500, 3500, 3500,
    3500, 3500, 3500, 3500, 3500, 3500, 3500, 3500, 3500, 3500,
    3500, 3500, 3500, 3500, 3500, 3500, 3500, 3500, 3500, 3500,
    3500, 3500, 3500, 3500, 3500, 3500, 3500, 3500, 3500, 3500,
    3500, 3500, 3500, 3500, 3500, 3500, 3500, 3500, 3500, 3500,
    3500, 3500, 3500, 3500, 3500, 3500, 3500, 3500, 3500, 3500,
    3500, 3500, 3500, 3500, 3500, 3500, 3500, 3500, 3500, 3500,
    3500, 3500, 3500, 3500, 3500, 3500, 3500, 3500, 3500, 3500,
    3500, 3500, 3500, 3500, 3500, 3500, 3500, 3500, 3500, 3500,
    3500, 3500, 3500, 3500, 3500, 3500, 3500, 3500, 3500, 3500,
    3500, 3500, 3500, 3500, 3500, 3500, 3500, 3500, 3500, 3500,
    3500, 3500, 3500, 3500, 3500, 3500, 3500, 3500, 3500, 3500,
    3500, 3500, 3500, 3500, 3500, 3500, 3500, 3500, 3500, 3500,
    3500, 3500, 3500, 3500, 3500, 3500, 3500, 3500, 3500, 3500,
    3500, 3500, 3500, 3500, 3500, 3500, 3500, 3500, 3500, 3500,
    3500, 3500, 3500, 3500, 3500, 3500, 3500, 3500, 3500, 3500,
    3500, 3500, 3500, 3500, 3500, 3500, 3500, 3500, 3500, 3500,
    3500, 3500, 3500, 3500, 3500, 3500, 3500, 3500, 3500, 3500,
    3500, 3500, 3500, 3500, 3500, 3500, 3500, 3500, 3500, 3500,
    3500, 3500, 3500, 3500, 3500, 3500, 3500, 3500, 3500, 3500,
    3500, 3500, 3500, 3500, 3500, 3500, 3500, 3500, 3500, 3500,
    3500, 3500, 3500, 3500, 3500, 3500, 3500, 3500, 3500, 3500,
    3500, 3500, 3500, 3500, 3500, 3500, 3500, 3500, 3500, 3500,
    3500, 3500, 3500, 3500, 3500, 3500, 3500, 3500, 3500, 3500,
    3500, 3500, 3500, 3500, 3500, 3500, 3500, 3500, 3500, 3500,
    3500, 3500, 3500, 3500, 3500, 3500, 3500, 3500, 3500, 3500,
    3500, 3500, 3500, 3500, 3500, 3500, 3500, 3500, 3500, 3500,
    3500, 3500, 3500, 3500, 3500, 3500, 3500, 3500, 3500, 3500,
    3500, 3500, 3500, 3500, 3500, 3500, 3500, 3500, 3500, 3500,

    3500, 3500, 3500, 3500, 3500, 3500, 3500, 3500, 3500, 3500,
    3500, 3500, 3500, 3500, 3500, 3500, 3500, 3500, 3496, 3490, 
    3483, 3475, 3466, 3454, 3440, 3423, 3404, 3382, 3357, 3329, 
    3297, 3263, 3224, 3180, 3134, 3086, 3033, 2977, 2918, 2856, 
    2789, 2718, 2645, 2568, 2486, 2399, 2309, 2212, 2110, 2000,
};

/*********************************************************************
 * @fn      Dac_Init
 *
 * @brief   Initializes DAC collection.
 *
 * @return  none
 */
static void Dac_Init(void)
{
    GPIO_InitTypeDef GPIO_InitStructure = {0};
    DAC_InitTypeDef  DAC_InitType = {0};

    RCC_APB2PeriphClockCmd(RCC_APB2Periph_GPIOA, ENABLE);
    RCC_APB1PeriphClockCmd(RCC_APB1Periph_DAC, ENABLE);

    GPIO_InitStructure.GPIO_Pin = GPIO_Pin_0;
    GPIO_InitStructure.GPIO_Mode = GPIO_Mode_Out_PP;
    GPIO_InitStructure.GPIO_Speed = GPIO_Speed_50MHz;
    GPIO_Init(GPIOA, &GPIO_InitStructure);
    GPIO_ResetBits(GPIOA, GPIO_Pin_0);

    GPIO_InitStructure.GPIO_Pin = GPIO_Pin_1;
    GPIO_InitStructure.GPIO_Mode = GPIO_Mode_Out_PP;
    GPIO_InitStructure.GPIO_Speed = GPIO_Speed_50MHz;
    GPIO_Init(GPIOA, &GPIO_InitStructure);
    GPIO_ResetBits(GPIOA, GPIO_Pin_1);

    GPIO_InitStructure.GPIO_Pin = GPIO_Pin_4;
    GPIO_InitStructure.GPIO_Mode = GPIO_Mode_AIN;
    GPIO_InitStructure.GPIO_Speed = GPIO_Speed_50MHz;
    GPIO_Init(GPIOA, &GPIO_InitStructure);
    GPIO_SetBits(GPIOA, GPIO_Pin_4);

    DAC_InitType.DAC_Trigger = DAC_Trigger_None;
    DAC_InitType.DAC_WaveGeneration = DAC_WaveGeneration_None;
    DAC_InitType.DAC_LFSRUnmask_TriangleAmplitude = DAC_LFSRUnmask_Bit0;
    DAC_InitType.DAC_OutputBuffer = DAC_OutputBuffer_Enable;
    DAC_Init(DAC_Channel_1, &DAC_InitType);
    DAC_Cmd(DAC_Channel_1, ENABLE);

    DAC_SetChannel1Data(DAC_Align_12b_R, 0);
}

static void dac_simulation_curve_generate(void)
{
    static uint8_t simulation_curve_flag_temp = 0;
    if (simulation_curve_flag_temp != simulation_curve_flag) {
        simulation_curve_flag_temp = simulation_curve_flag;
        if (simulation_curve_flag) {
            multi_key_Judg_cnt = 0;
            simulation_curve_cnt = 0;
            simulation_curve_time = get_tim4_10us();
            simulation_curve_data_invalid = 0;
            test_sta = 1;
            simulation_curve_single_trigger_cnt = 0;
            simulation_curve_single_release_cnt = 0;
            simulation_curve_trigger_delay_time = 0;
            simulation_curve_release_delay_time = 0;
            key_trigger_cnt = 0;
            waveIndex = 0;
            simulation_curve_timeout = 6;
            DAC_SetChannel1Data(DAC_Align_12b_R, sineWaveTable[waveIndex]);
            HALL_LDO_EN(1);
            memset(simulation_curve_trigger_delay_time_buf, 0xff, sizeof(simulation_curve_trigger_delay_time_buf));
            memset(simulation_curve_release_delay_time_buf, 0xff, sizeof(simulation_curve_release_delay_time_buf));
            printf("Simulation Curve Mode Delay Test Start\r\n");
        } else {
            test_sta = 2;
            HALL_LDO_EN(0);
            printf("Simulation Curve Mode Delay Test Finsh\r\n");
        }
    }

    if (simulation_curve_flag) {
        if (get_tim4_dt_10us(simulation_curve_time) >= simulation_curve_timeout) {
            if (waveIndex++ >= SINE_WAVE_POINTS) {
                waveIndex = 0;
                ++simulation_curve_cnt;
            }

            if (waveIndex == 430) {
                if (simulation_curve_cnt == 2) {
                    if (multi_key_Judg_cnt == 0 && test_cnt_mode == 0) {
                        simulation_curve_flag = 0;
                        lcd_test_data_anomaly_set(2);
                    }
                }
                simulation_curve_release_flag = 1;
                simulation_curve_single_release_cnt = 0;
                multi_key_Judg_cnt = 0;
                // printf("start key lift, tim4 tick: %d\r\n", get_tim4_10us());
            }

            if (waveIndex == 967) {
                if (simulation_curve_cnt == 2) {
                    if (multi_key_Judg_cnt == 0 && test_cnt_mode == 0) {
                        simulation_curve_flag = 0;
                        lcd_test_data_anomaly_set(2);
                    }
                }
                simulation_curve_press_flag = 1;
                simulation_curve_single_trigger_cnt = 0;
                multi_key_Judg_cnt = 0;
                // printf("start key press, tim4 tick: %d\r\n", get_tim4_10us());
            }
            DAC_SetChannel1Data(DAC_Align_12b_R, sineWaveTable[waveIndex]);
            simulation_curve_time = get_tim4_10us();
            if (multi_key_Judg_cnt >= 2 && test_cnt_mode == 0) {
                simulation_curve_flag = 0;
                printf("The keyboard has a double touch issue, sending %d packets in a single press or release event.\r\n", multi_key_Judg_cnt);
                multi_key_Judg_cnt = 0;
                printf("simulation_curve_cnt == %d\r\n", simulation_curve_cnt);
                if (simulation_curve_cnt == 0) 
                    simulation_curve_cnt = 1;

                if (simulation_curve_cnt == 1) {
                    test_cnt = simulation_curve_cnt;
                } else {
                    test_cnt = simulation_curve_cnt - 1;
                }
            }
        }
    }

    if (simulation_curve_cnt >= test_cnt) {
        DAC_SetChannel1Data(DAC_Align_12b_R, 0);
        HALL_LDO_EN(0);
        simulation_curve_cnt = 0;
        simulation_curve_flag = 0;
        if (test_cnt_mode) {
            if (key_trigger_cnt > ((test_cnt << 1) + 1)) {
                printf("key trigger cnt: %d\r\n", key_trigger_cnt);
                simulation_curve_data_invalid = 1;
            } else {
                printf("key trigger cnt: %d\r\n", key_trigger_cnt);
            }
        } else {
            lcd_test_cnt_set(test_cnt);
        }

        for (uint8_t i = 0; i < test_cnt; i++) {
            printf("simulation_curve_trigger_delay_time_buf[%d]: %d\r\n", i, simulation_curve_trigger_delay_time_buf[i]);
        }
        for (uint8_t i = 0; i < test_cnt; i++) {
            printf("simulation_curve_release_delay_time_buf[%d]: %d\r\n", i, simulation_curve_release_delay_time_buf[i]);
        }
        for (uint8_t i = 0; i < test_cnt; i++) {
            simulation_curve_trigger_delay_time += simulation_curve_trigger_delay_time_buf[i];
            simulation_curve_release_delay_time += simulation_curve_release_delay_time_buf[i];
            if (simulation_curve_trigger_delay_time_buf[i] == 0xffff || simulation_curve_trigger_delay_time_buf[i] > 30000) {
                simulation_curve_data_invalid = 2;
                break;
            }
            if (simulation_curve_release_delay_time_buf[i] == 0xffff || simulation_curve_release_delay_time_buf[i] > 30000) {
                simulation_curve_data_invalid = 2;
                break;
            }
        }
        simulation_curve_trigger_delay_time = simulation_curve_trigger_delay_time / test_cnt;
        simulation_curve_release_delay_time = simulation_curve_release_delay_time / test_cnt;
        if (simulation_curve_data_invalid) {
            simulation_curve_trigger_delay_time = 0;
            simulation_curve_release_delay_time = 0;
            lcd_test_data_anomaly_set(simulation_curve_data_invalid);
        } else {
            lcd_press_delay_time_set(simulation_curve_trigger_delay_time);
            lcd_lift_delay_time_set(simulation_curve_release_delay_time);
            printf("trigger delay time: %d\r\n", simulation_curve_trigger_delay_time);
            printf("release delay time: %d\r\n", simulation_curve_release_delay_time);
        }
        if (test_cnt_mode == 0) {
            test_cnt = 100;
        } else if (test_cnt_mode == 1) {
            test_cnt = 1;
        } else if (test_cnt_mode == 2) {
            test_cnt = 10;
        } else if (test_cnt_mode == 3) {
            test_cnt = 100;
        }
    }

}
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
int main( void )
{
    /* Initialize system configuration */
    SystemCoreClockUpdate( );
    Delay_Init( );
    USART_Printf_Init( 115200 );
    
    printf( "SystemClk:%d\r\n", SystemCoreClock );
    printf( "ChipID:%08x\r\n", DBGMCU_GetCHIPID() );
    printf( "Delay Tester\r\n" );

    /* Initialize TIM2, Time base: 1ms  */
    TIM2_Init((1000 - 1), ((SystemCoreClock / 1000 / 1000) - 1));

    /* Initialize TIM4, Time base: 10us */
    TIM4_Init((10 - 1), ((SystemCoreClock / 1000 / 1000) - 1));

    /* Initialize TIM3, Time base: 10us */
    TIM3_Init( 9, (SystemCoreClock / 1000 / 1000) - 1 );

    Dac_Init();	

    swkey_init();

    lcd_init();

    /* Initialize USBHS host */
    /* Note: Only CH32V305/CH32V307 support USB high-speed port. */
#if DEF_USBHS_PORT_EN
    printf( "USBHS Host Init\r\n" );
    USBHS_RCC_Init( );
    USBHS_Host_Init( ENABLE );
    memset( &RootHubDev[ DEF_USBHS_PORT_INDEX ].bStatus, 0, sizeof( ROOT_HUB_DEVICE ) );
    memset( &HostCtl[ DEF_USBHS_PORT_INDEX * DEF_ONE_USB_SUP_DEV_TOTAL ].InterfaceNum, 0, DEF_ONE_USB_SUP_DEV_TOTAL * sizeof( HOST_CTL ) );
#endif

    /* Initialize USBFS host */
#if DEF_USBFS_PORT_EN
    printf( "USBFS Host Init\r\n" );
    USBFS_RCC_Init( );
    USBFS_Host_Init( ENABLE );
    memset( &RootHubDev[ DEF_USBFS_PORT_INDEX ].bStatus, 0, sizeof( ROOT_HUB_DEVICE ) );
    memset( &HostCtl[ DEF_USBFS_PORT_INDEX * DEF_ONE_USB_SUP_DEV_TOTAL ].InterfaceNum, 0, DEF_ONE_USB_SUP_DEV_TOTAL * sizeof( HOST_CTL ) );
#endif
    
    while( 1 )
    {
        static uint8_t sta;
        if (sta != dev_sta) {
            sta = dev_sta;
            if (dev_sta) {
                lcd_device_state_set(dev_sta);
                lcd_product_name_set(product_name);
            } else {
                lcd_device_state_set(dev_sta);
                test_sta = 0;
            }
        }

        static uint8_t mode;
        if (mode != test_mode) {
            mode = test_mode;
            lcd_test_mode_set(test_mode);
        }

        static uint8_t test_sta_temp;
        if (test_sta_temp != test_sta) {
            test_sta_temp = test_sta;
            lcd_test_state_set(test_sta);
        }

        static uint32_t press_delay_time;
        if (press_delay != press_delay_time) {
            press_delay_time = press_delay;
            lcd_press_delay_time_set(press_delay);
        }

        static uint32_t lift_delay_time;
        if (lift_delay != lift_delay_time) {
            lift_delay_time = lift_delay;
            lcd_lift_delay_time_set(lift_delay);
        }

        swkey_loop();

        USBH_MainDeal( );

        if (test_mode == 0) {
            dac_simulation_curve_generate();
        } else if (test_mode == 1) {
            dac_square_wave_wave_generate();
        } else if (test_mode == 2) {
            dac_triangle_wave_generate();
        }

    }
}

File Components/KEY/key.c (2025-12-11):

/* Copyright 2025 Ender Chan (Ender)
 *
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
 * You should have received a copy of the GNU General Public License
 * along with this program.  If not, see <http://www.gnu.org/licenses/>.
 */

#include "key.h"
#include "tim.h"
#include "lcd.h"

const _Hw_Cs_Gpio_t hw_sw_cfg_tbl[SW_KEY_NUM] = {
    {GPIOC, GPIO_Pin_1, Bit_RESET},
    {GPIOC, GPIO_Pin_2, Bit_RESET},
    {GPIOC, GPIO_Pin_8, Bit_RESET},
    {GPIOC, GPIO_Pin_9, Bit_RESET},
};

// 按键配置数组
static ButtonConfig buttons[SW_KEY_NUM] = {
    { BUTTON_STATE_IDLE, 0, 0, 0, 0, BUTTON_NONE },
    { BUTTON_STATE_IDLE, 0, 0, 0, 0, BUTTON_NONE },
    { BUTTON_STATE_IDLE, 0, 0, 0, 0, BUTTON_NONE },
    { BUTTON_STATE_IDLE, 0, 0, 0, 0, BUTTON_NONE }
};

extern uint8_t  square_wave_flag;
extern uint8_t  triangle_wave_flag;
extern uint8_t  simulation_curve_flag;
extern uint8_t  test_mode;
extern uint8_t  test_sta;
extern uint8_t  test_cnt;
extern uint8_t  test_cnt_mode;
extern uint8_t  test_trig_first_flag;

static void swkey1_short_press_handle(void)
{
    printf("swkey1_short_press_handle\r\n");
    if (simulation_curve_flag || square_wave_flag || triangle_wave_flag)
        return;

    if (++test_cnt_mode >= 4) {
        test_cnt_mode = 0;
    }
    if (test_cnt_mode == 0) {
        test_cnt = 100;
        lcd_test_cnt_set(0);
    } else if (test_cnt_mode == 1) {
        test_cnt = 1;
        lcd_test_cnt_set(1);
    } else if (test_cnt_mode == 2) {
        test_cnt = 10;
        lcd_test_cnt_set(10);
    } else if (test_cnt_mode == 3) {
        test_cnt = 100;
        lcd_test_cnt_set(100);
    }
    
}

static void swkey1_long_press_start_handle(void)
{
    printf("swkey1_long_press_start_handle\r\n");
}

static void swkey1_long_press_end_handle(void)
{
    printf("swkey1_long_press_end_handle\r\n");
}

static void swkey1_double_click_handle(void)
{
    printf("swkey1_double_click_handle\r\n");
}

static void swkey2_short_press_handle(void)
{
    printf("swkey2_short_press_handle\r\n");
    if (simulation_curve_flag || square_wave_flag || triangle_wave_flag)
        return;

    if (++test_mode > 2)
        test_mode = 0;
}

static void swkey2_long_press_start_handle(void)
{
    printf("swkey2_long_press_start_handle\r\n");
}

static void swkey2_long_press_end_handle(void)
{
    printf("swkey2_long_press_end_handle\r\n");
}

static void swkey2_double_click_handle(void)
{
    printf("swkey2_double_click_handle\r\n");
}

static void swkey3_short_press_handle(void)
{
    printf("swkey3_short_press_handle\r\n");
    if (test_mode == 0) {
        simulation_curve_flag = 1;
    } else if (test_mode == 1) {
        square_wave_flag = 1;
    } else if (test_mode == 2) {
        triangle_wave_flag = 1;
    }
    if (test_cnt_mode == 0) {
        test_cnt = 100;
        lcd_test_cnt_set(0);
    } else if (test_cnt_mode == 1) {
        test_cnt = 1;
        lcd_test_cnt_set(1);
    } else if (test_cnt_mode == 2) {
        test_cnt = 10;
        lcd_test_cnt_set(10);
    } else if (test_cnt_mode == 3) {
        test_cnt = 100;
        lcd_test_cnt_set(100);
    }
    test_trig_first_flag = 0;
}

static void swkey3_long_press_start_handle(void)
{
    printf("swkey3_long_press_start_handle\r\n");
}

static void swkey3_long_press_end_handle(void)
{
    printf("swkey3_long_press_end_handle\r\n");
}

static void swkey3_double_click_handle(void)
{
    printf("swkey3_double_click_handle\r\n");
}

static void swkey4_short_press_handle(void)
{
    printf("swkey4_short_press_handle\r\n");
    simulation_curve_flag = 0;
    square_wave_flag = 0;
    triangle_wave_flag = 0;
    HALL_LDO_EN(0);
    test_sta = 2;
    lcd_test_data_anomaly_set(2);
}

static void swkey4_long_press_start_handle(void)
{
    printf("swkey4_long_press_start_handle\r\n");
}

static void swkey4_long_press_end_handle(void)
{
    printf("swkey4_long_press_end_handle\r\n");
}

static void swkey4_double_click_handle(void)
{
    printf("swkey4_double_click_handle\r\n");
}

// 按键功能映射
static func buttonFunction[SW_KEY_NUM][4] = {
    // 按键处理: 短按, 长按开始, 长按结束, 双击
    { swkey1_short_press_handle, swkey1_long_press_start_handle, swkey1_long_press_end_handle, swkey1_double_click_handle },
    { swkey2_short_press_handle, swkey2_long_press_start_handle, swkey2_long_press_end_handle, swkey2_double_click_handle },
    { swkey3_short_press_handle, swkey3_long_press_start_handle, swkey3_long_press_end_handle, swkey3_double_click_handle },
    { swkey4_short_press_handle, swkey4_long_press_start_handle, swkey4_long_press_end_handle, swkey4_double_click_handle }
};

// 按键状态处理
static ButtonEvent button_event_process(uint8_t id)
{
    ButtonConfig* btn = &buttons[id];
    uint32_t now = get_sys_time_ms();
    uint8_t btnStateNow = GPIO_ReadInputDataBit(hw_sw_cfg_tbl[id].GPIOx, hw_sw_cfg_tbl[id].Pin);
    ButtonEvent event = BUTTON_NONE;

    // 按键状态机
    switch (btn->state) {
        case BUTTON_STATE_IDLE:
            if (btnStateNow == RESET) { // 按键按下
                btn->pressStartTime = now;
                btn->state = BUTTON_STATE_PRESSED;
            }
            break;

        case BUTTON_STATE_PRESSED:
            if (btnStateNow != RESET) { // 按键释放
                // 防抖处理
                if ((now - btn->pressStartTime) > DEBOUNCE_TIME) {
                    btn->releaseTime = now;
                    btn->clickCount++;
                    btn->state = BUTTON_STATE_RELEASED;
                } else {
                    btn->state = BUTTON_STATE_IDLE; // 抖动，忽略
                }
            }
            // 检查长按开始
            else if ((now - btn->pressStartTime) > LONG_PRESS_MIN) {
                btn->state = BUTTON_STATE_LONG_PRESS;
                event = BUTTON_LONG_PRESS_START;
                btn->lastHoldTime = now;
            }
            break;

        case BUTTON_STATE_RELEASED:
            // 等待稳定
            if ((now - btn->releaseTime) > DEBOUNCE_TIME) {
                if (btn->clickCount == 1) {
                    // 启动双击检测
                    btn->state = BUTTON_STATE_WAIT_DOUBLE;
                } else if (btn->clickCount == 2) {
                    btn->state = BUTTON_STATE_IDLE;
                    btn->clickCount = 0;
                    event = BUTTON_DOUBLE_CLICK;
                }
            }
            break;

        case BUTTON_STATE_WAIT_DOUBLE:
            // 检测第二次按下
            if (btnStateNow == RESET) {
                btn->pressStartTime = now;
                btn->state = BUTTON_STATE_PRESSED;
            }
            // 双击超时
            else if ((now - btn->releaseTime) > DOUBLE_CLICK_MAX) {
                btn->state = BUTTON_STATE_IDLE;
                btn->clickCount = 0;

                // 检查是否为短按
                if ((btn->releaseTime - btn->pressStartTime) < SHORT_PRESS_MAX) {
                    event = BUTTON_SHORT_PRESS;
                }
            }
            break;
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

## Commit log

2025-09-13 docs: 1.新增LICENSE文件、README文档和《延时测试器操作说明.pdf》 2.新增WCH固件升级工具
2025-09-22 feat: 1.新增三角波模式，调整模式顺序，修复部分Bug 2.新增测试次数切换按键，分别为1、10、100、自动；自动模式遇到断触会停止 3.调整仿真点击曲线，取人手实际按压的前段波形，更贴近实际按压 4.更新烧录固件
    [app_km.c, key.c, key.h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]
2025-09-22 docs: 1.新增硬件原理图、PCB以及BOM等硬件资料 2.更新README文档
    [延时测试器.PrjPcb, 延时测试器.SchDoc, 延迟测试器BOM.xlsx]
2025-09-22 docs: 1.新增测试器操作教程、升级教程以及原理讲解视频资料 2.更新README文档
2025-09-27 fix: 1.修复自动测试失败停下来，但UI显示卡死的问题 2.测试延时时间超过30毫秒会显示异常 3.更新v0.0.6_20250925a版本烧录固件
    [main.c]
2025-09-28 docs: 更新延时测试器物料BOM表
    [延迟测试器BOM.xlsx]
2025-11-20 fix: 解决部分键盘会通过USB不同接口发送多次抬起事件导致的测量出错的问题
2025-12-11 fix: 1.解决部分键盘无法测试多键延时的问题 2.增加测试器版本号显示

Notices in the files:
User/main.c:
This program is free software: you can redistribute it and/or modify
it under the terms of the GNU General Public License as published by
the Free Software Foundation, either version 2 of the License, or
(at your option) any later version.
